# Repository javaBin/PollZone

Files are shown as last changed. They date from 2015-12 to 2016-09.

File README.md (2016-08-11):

# Arduino

Configure your Arduino IDE with ESP8266 support: File -> Preferences, add `http://arduino.esp8266.com/stable/package_esp8266com_index.json` under *Additional Board Manager URLs*.

Open the Board Manager: Tools -> Board -> Board Manager and add the `esp8266` board. Current version: `2.2.0`

# BOM - Bill of materials

For 20 bokser:

* 20 x grønn knapper
* 20 x gule knapper
* 20 x røde knapper
* 6 blanke PCBer
* loddetinn
* 20 NodeMCU 
* 20 usb-kabler (kanskje lange, spør hilde)
* 20 ladere
* 80 x distanseskruer 2-3mm
* 80 x maskinskruer til distanseskruer
* 20 x micro-usb-kontakter
* 60 x 1k ohm motstander
* 60 x 120 ohm til blå led
* 60 x 150 ohm til gul led
* 60 x 150 ohm til rød led
* 60 x kondensator
* 240 sko "ca størrelse 15"
* ledninger 

# TODOs

## Box

Modifiser trekasse.
- Litt lavere
- Skjære ut små hull for "feste-tapper" i led-lysene
- USB-utgang på sidevegg
- Gravere inn logo
- plexiglass/akryl
- 3d-printe mounting-brackets for usb.
- Huske å legg panelet riktig vei slik at "svidde kanter" hanver på innsiden.

Avklaringer:
- 2.4GHz nett i spektrum
- Spør om det er strøm ved bordene

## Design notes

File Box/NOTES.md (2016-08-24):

# 2016-08-23

* første runde: 300mm/s 7%/10% (kjører to ganger pga svg-filen)
* andre runde: 300mm/s 7%/15% (kjører to ganger pga svg-filen)

## Gravering

Test 1: 14mm/s 95% corner, 100% work

Test 2: 9mm/s 75% corner, 100% work. Forsatt noen områder som ikke kuttes. Hjørnene ble mye bedre med en god del mindre effekt.

## Eksperimentering med laserkutter:

1. 150mm/s, 7%/30%
1. 100mm/s, 7%/20%
1. Best: samme som II, 12,5mm ute av fokus

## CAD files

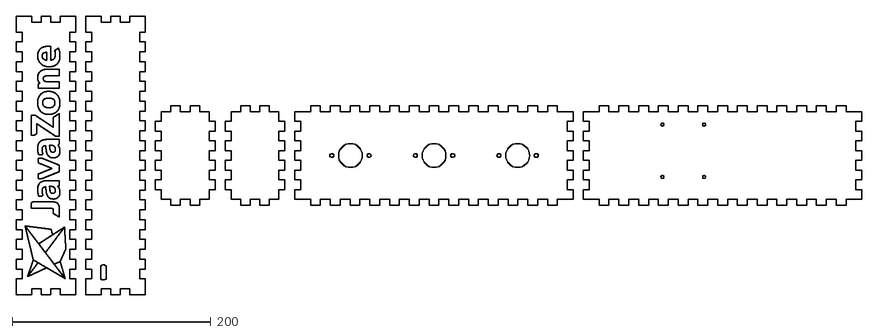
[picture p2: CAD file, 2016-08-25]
Box/box-2016-08-25.dxf
850.0 x 280.0

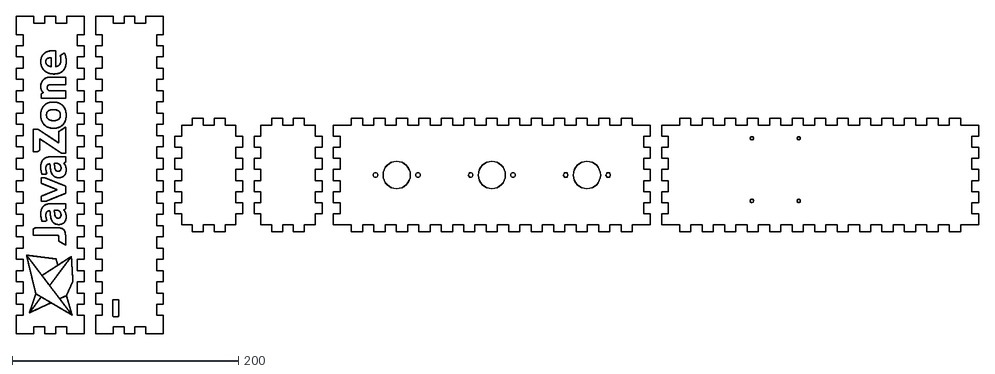
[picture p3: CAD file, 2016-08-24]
Box/box-2016-08-23.dxf
850.0 x 280.0

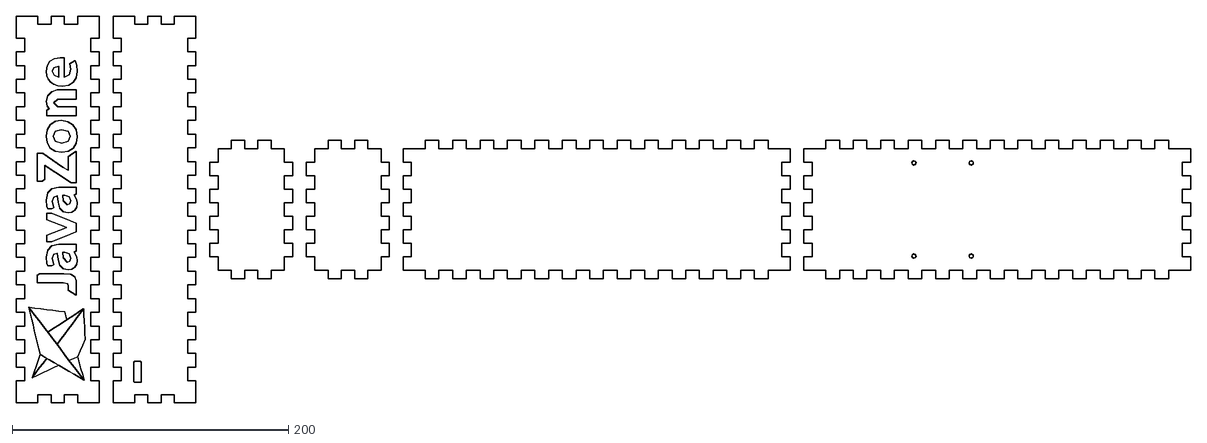
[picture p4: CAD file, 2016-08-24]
Box/box-2016-08-22.dxf
850.0 x 280.0

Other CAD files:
Box/PollZone.fcstd

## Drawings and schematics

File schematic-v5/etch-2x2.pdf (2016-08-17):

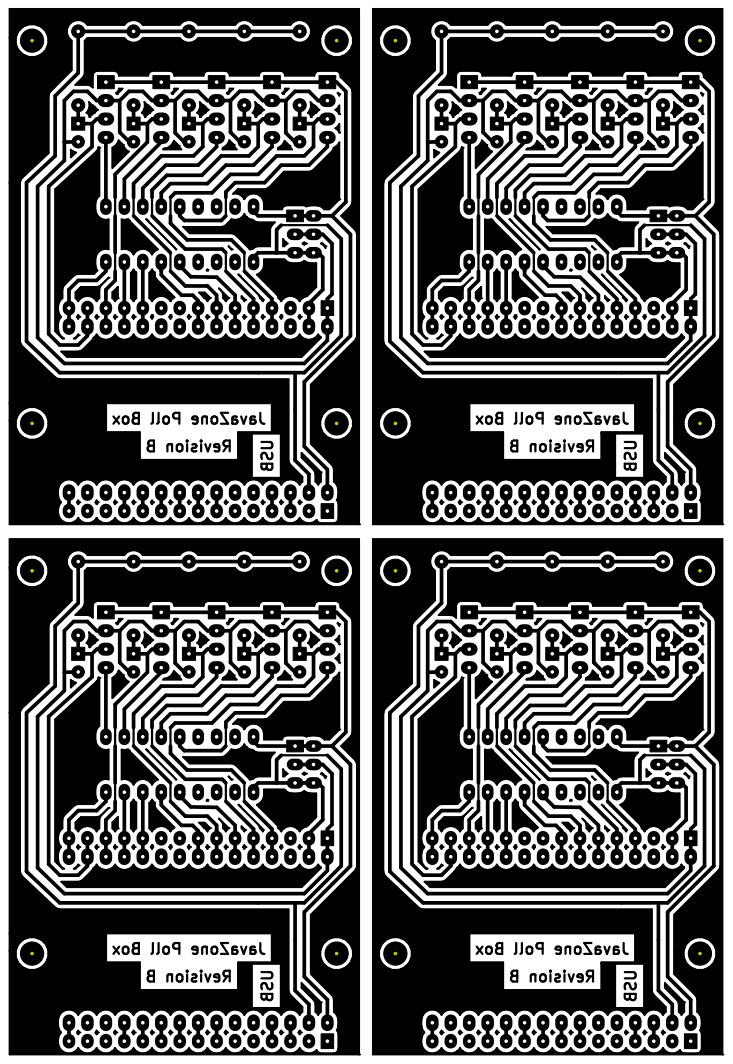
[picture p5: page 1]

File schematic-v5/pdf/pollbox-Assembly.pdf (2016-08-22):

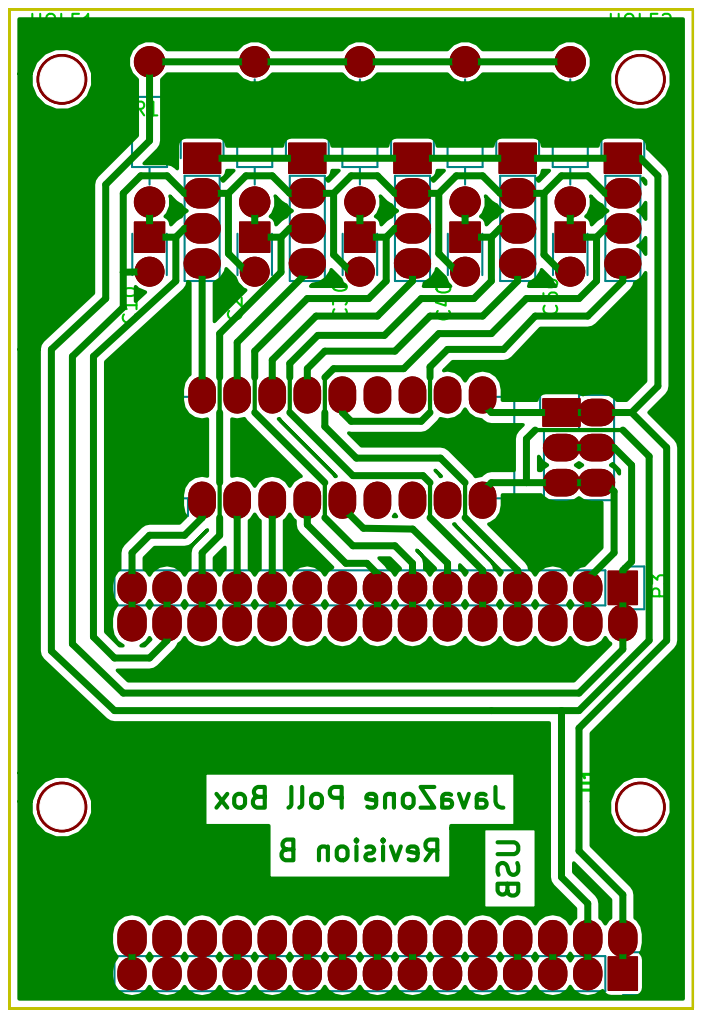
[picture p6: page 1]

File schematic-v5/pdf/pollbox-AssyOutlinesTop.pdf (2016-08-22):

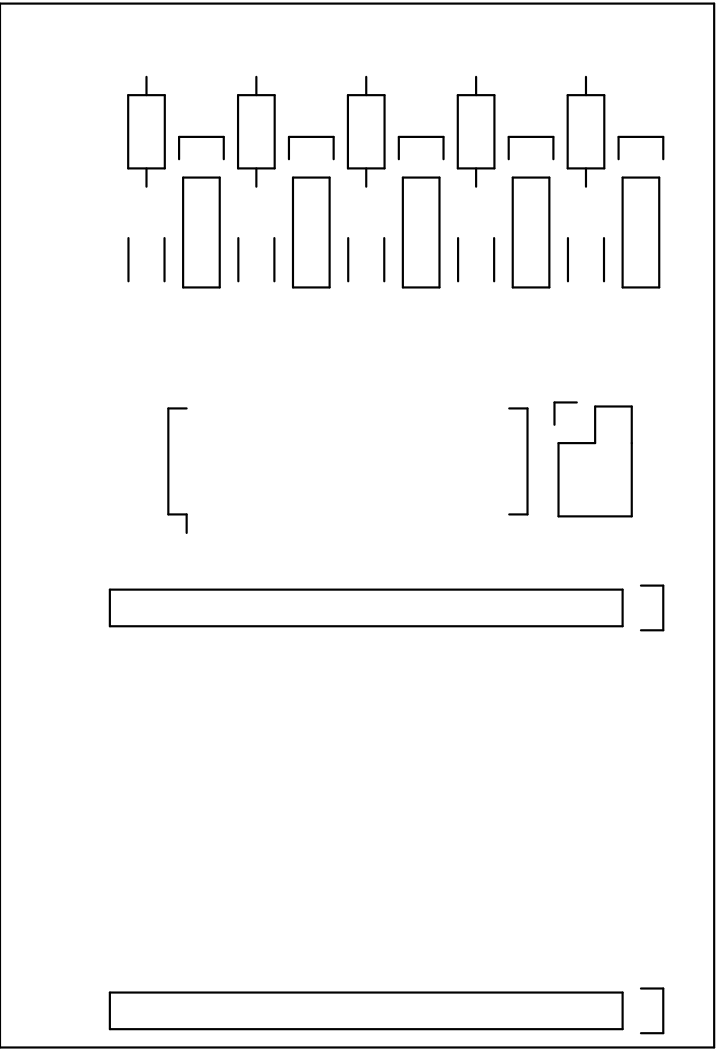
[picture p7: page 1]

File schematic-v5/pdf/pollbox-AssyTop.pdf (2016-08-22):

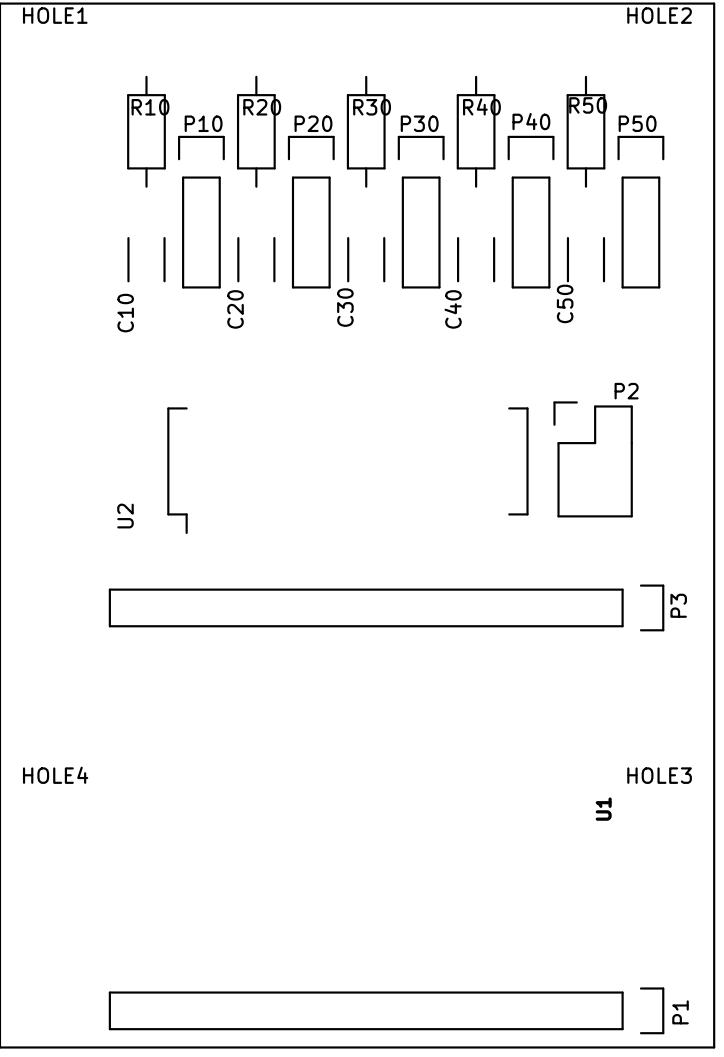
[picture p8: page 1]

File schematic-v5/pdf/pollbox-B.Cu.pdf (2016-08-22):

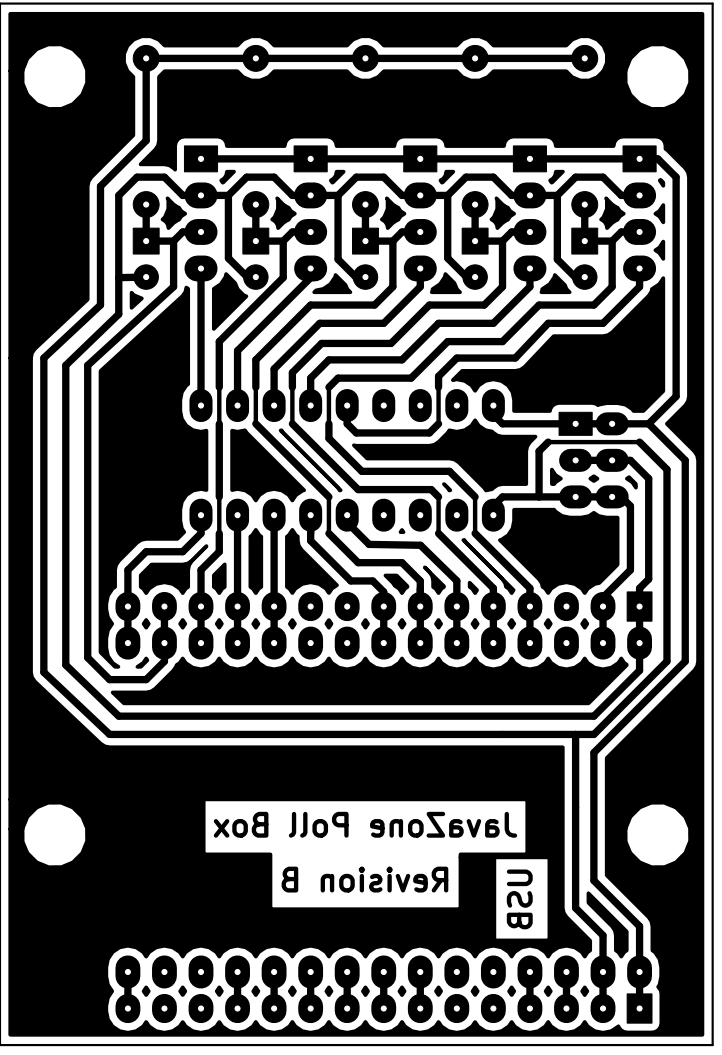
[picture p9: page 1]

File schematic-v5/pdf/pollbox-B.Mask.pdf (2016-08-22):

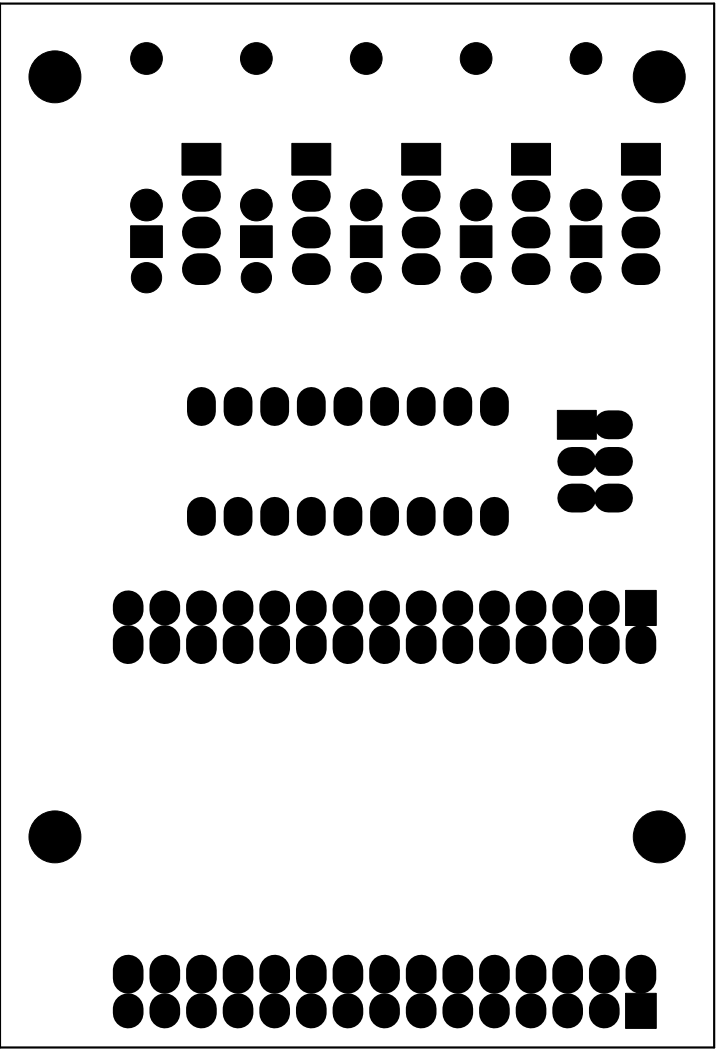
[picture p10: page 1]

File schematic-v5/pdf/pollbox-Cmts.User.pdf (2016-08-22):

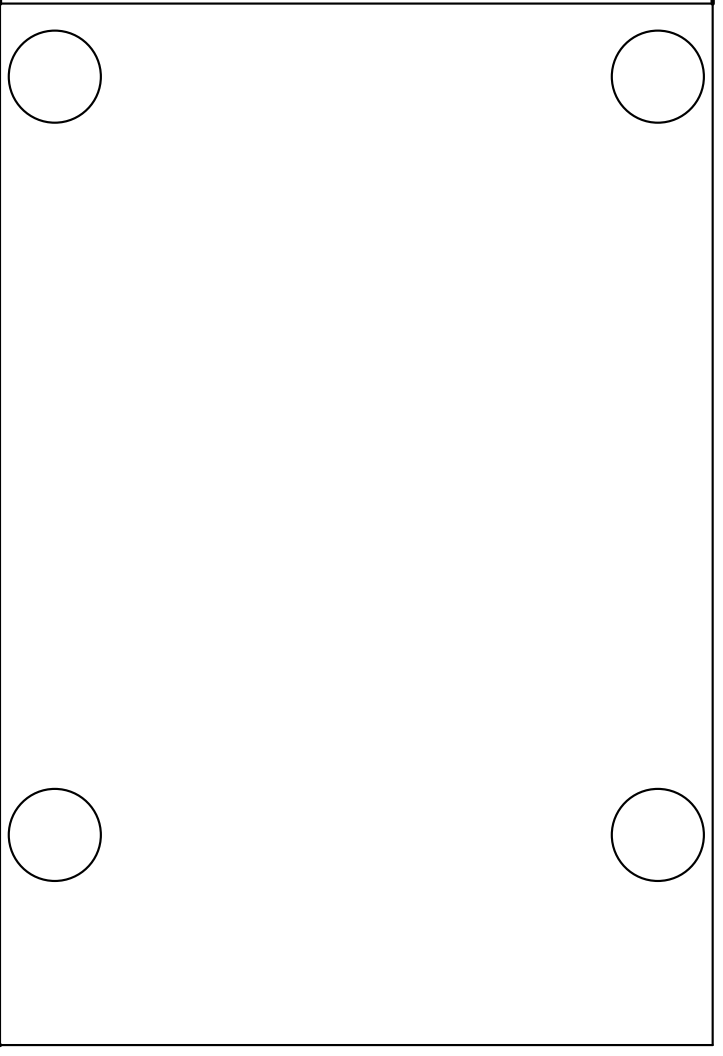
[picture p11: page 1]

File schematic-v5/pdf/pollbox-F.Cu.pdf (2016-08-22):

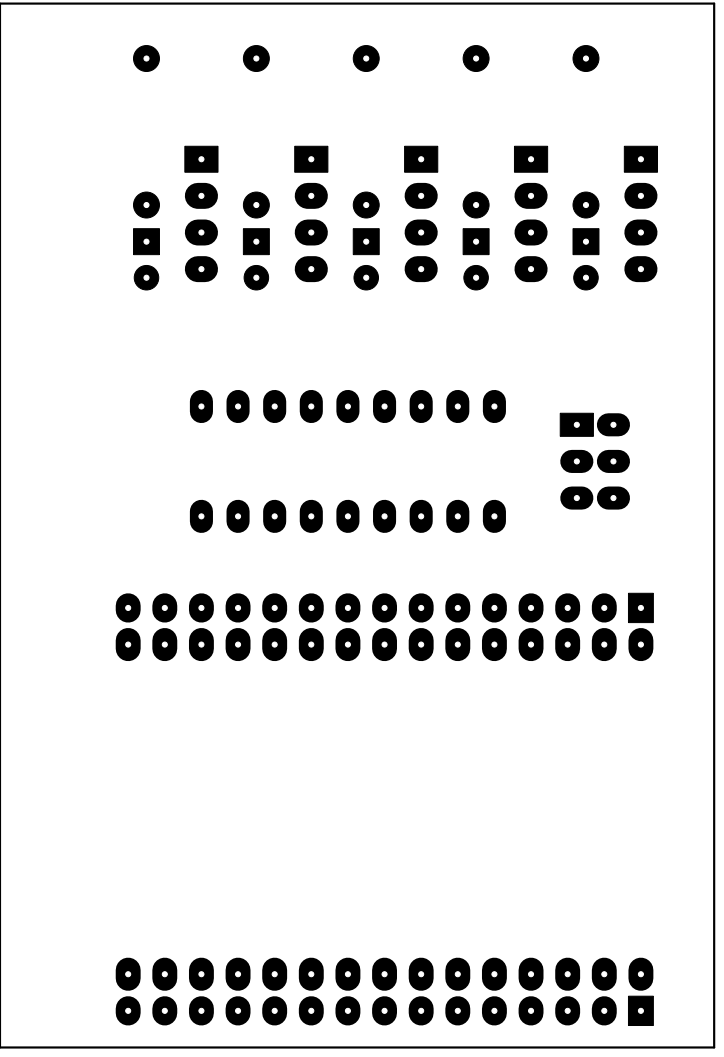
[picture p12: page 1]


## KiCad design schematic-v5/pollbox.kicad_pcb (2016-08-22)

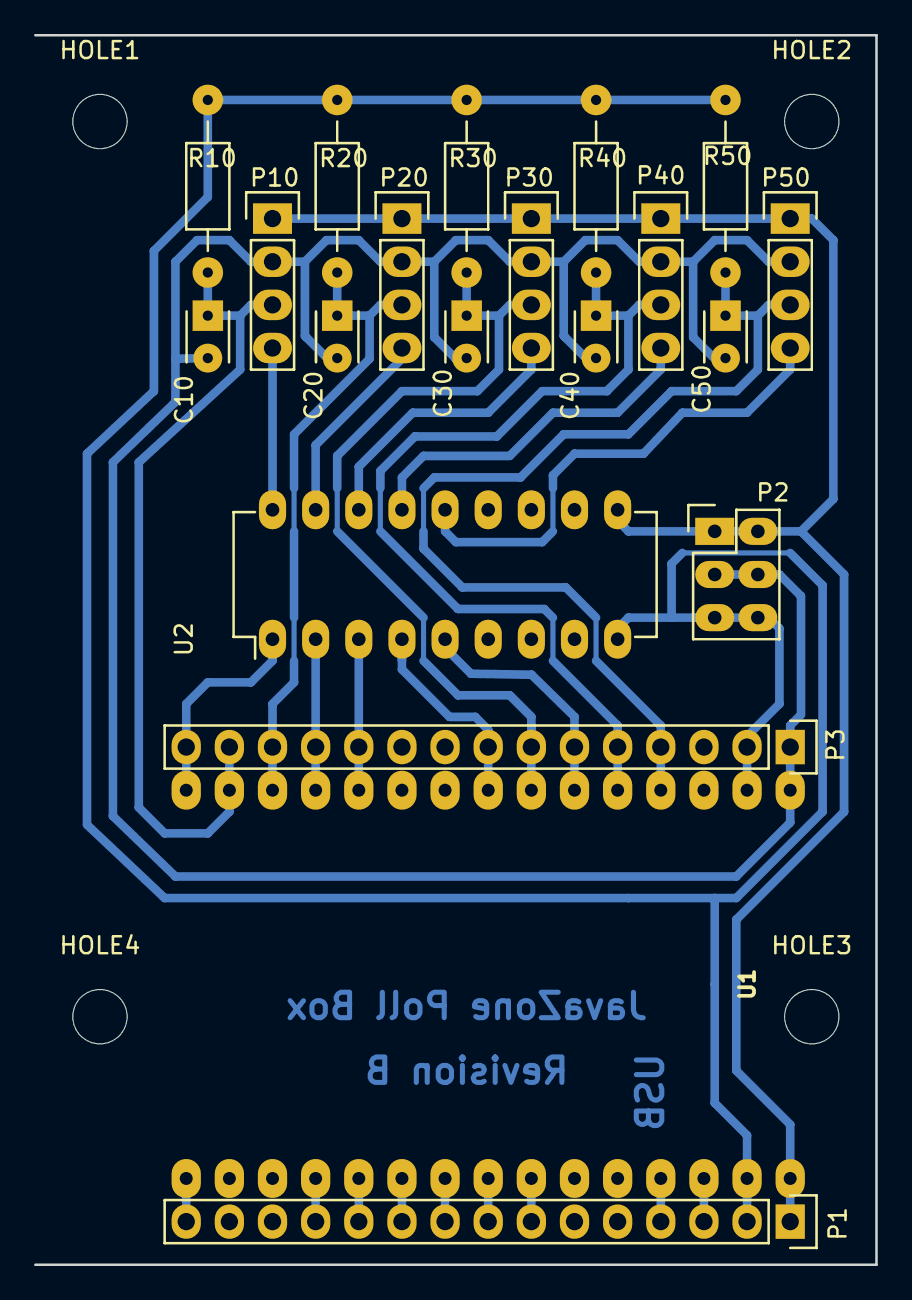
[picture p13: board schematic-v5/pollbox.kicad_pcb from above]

Board: 2 copper layers, 49.5 x 72.4 mm, 24 parts (0 on the bottom side), 27 nets.

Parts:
C10, C20, C30, C40, C50: 100n; C_Disc_D3_P2.5
HOLE1: M1; MountingHole_3.2mm_M3
HOLE2: M2; MountingHole_3.2mm_M3
HOLE3: M4; MountingHole_3.2mm_M3
HOLE4: M3; MountingHole_3.2mm_M3
P1, P3: Pin_Header_Straight_1x15
P2: Power; Pin_Header_Straight_2x03
P10: SW_1; Pin_Header_Straight_1x04
P20: SW_2; Pin_Header_Straight_1x04
P30: SW_3; Pin_Header_Straight_1x04
P40: SW_4; Pin_Header_Straight_1x04
P50: SW_5; Pin_Header_Straight_1x04
R10, R20, R30, R40, R50: 10k; Resistor_Horizontal_RM10mm
U1: NodeMCU_1.0; NodeMCU
U2: ULN2803; DIP-18_W7.62mm_LongPads

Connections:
+3V3: C10.2, C20.2, C30.2, C40.2, C50.2, P2.3, P2.4, P3.1, P10.2, P20.2, P30.2, P40.2, P50.2, U1.30
+5V: P1.1, P2.1, P2.2, P10.1, P20.1, P30.1, P40.1, P50.1, U1.1, U2.10
/AD0: P1.15, U1.15
/CLK: P1.7, U1.7
/CMD: P1.9, U1.9
/EN: P1.4, U1.4
/LED_1: P3.15, U1.16, U2.1
/LED_1_OUT: P10.4, U2.18
/LED_2: P3.12, U1.19, U2.2
/LED_2_OUT: P20.4, U2.17
/LED_3: P3.11, U1.20, U2.3
/LED_3_OUT: P30.4, U2.16
/LED_4: P3.8, U1.23, U2.4
/LED_4_OUT: P40.4, U2.15
/LED_5: P3.6, U1.25, U2.5
/LED_5_OUT: P50.4, U2.14
/SD0: P1.8, U1.8
/SD1: P1.10, U1.10
/SD2: P1.11, U1.11
/SD3: P1.12, U1.12
/SWITCH_1: C10.1, P3.14, P10.3, R10.1, U1.17
/SWITCH_2: C20.1, P3.13, P20.3, R20.1, U1.18
/SWITCH_3: C30.1, P3.7, P30.3, R30.1, U1.24
/SWITCH_4: C40.1, P3.5, P40.3, R40.1, U1.26
/SWITCH_5: C50.1, P3.4, P50.3, R50.1, U1.27
/~RST: P1.3, U1.3
GND: P1.2, P2.5, P2.6, P3.2, R10.2, R20.2, R30.2, R40.2, R50.2, U1.2, U1.29, U2.9

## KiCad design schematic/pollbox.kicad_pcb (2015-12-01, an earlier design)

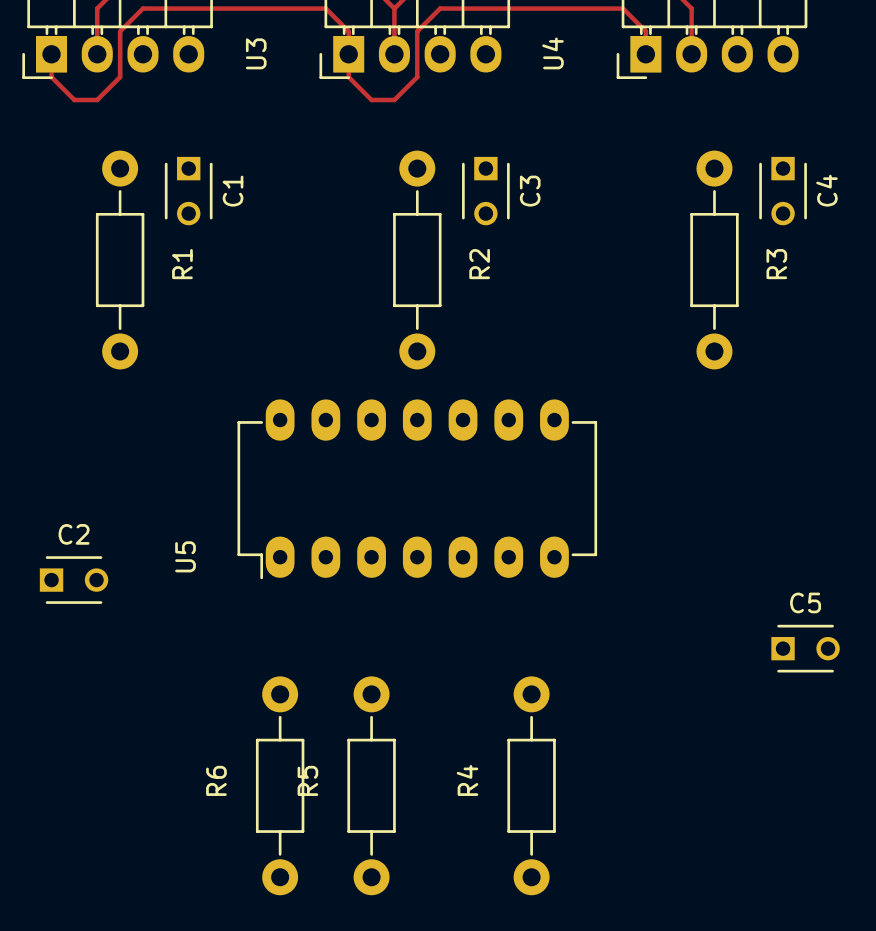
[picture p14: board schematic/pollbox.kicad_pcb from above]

Board: 2 copper layers, 15 parts (0 on the bottom side), 12 nets.

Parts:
C1, C2, C3, C4, C5: 100n; C_Disc_D3_P2.5
R1, R2, R3: 10k; Resistor_Horizontal_RM10mm
R4, R5, R6: 1k; Resistor_Horizontal_RM10mm
U2, U3, U4: BIG_BUTTON; Pin_Header_Angled_1x04
U5: LM3046; DIP-14_W7.62mm_LongPads

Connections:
+3V3: C1.2, C3.2, C4.2, C5.2, U2.1, U3.1, U4.1
+5V: C2.1, U2.2, U3.2, U4.2
GND: C2.2, C5.1, R1.2, R2.2, R3.2, U5.7, U5.10, U5.13
unnamed: C1.1, R1.1, U2.4
unnamed: C3.1, R2.1, U3.4
unnamed: C4.1, R3.1, U4.4
unnamed: R4.2, U5.6
unnamed: R5.2, U5.9
unnamed: R6.2, U5.12
unnamed: U2.3, U5.14
unnamed: U3.3, U5.11
unnamed: U4.3, U5.8

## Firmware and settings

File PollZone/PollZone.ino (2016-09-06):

#include "PollClient.h"
#include "PollState.h"
#include "Buttons.h"
#include "Cfg.h"
#include "utils.h"
#include <Arduino.h>
#include <ArduinoOTA.h>

Cfg cfg(__DATE__ " " __TIME__);
PollClient* pollClient;
PollState* pollState;
Buttons buttons;

int rotateSequence = 0;

void setupOta() {
  static fixed_interval_timer<1000> ota_blink;

  ArduinoOTA.onStart([]() {
    Serial.println("Starting OTA upgrade");
    ota_blink.reset();
    buttons.set_ota_mode(true);
  });
  ArduinoOTA.onEnd([]() {
    buttons.set_ota_mode(false);
    Serial.println("\nOTA upgrade complete");
  });
  ArduinoOTA.onProgress([](unsigned int progress, unsigned int total) {
    Serial.printf("Progress: %u%%\r", (progress / (total / 100)));
    buttons.loop();
  });
  ArduinoOTA.onError([](ota_error_t error) {
    Serial.printf("Error[%u]: ", error);
    if (error == OTA_AUTH_ERROR) Serial.println("Auth Failed");
    else if (error == OTA_BEGIN_ERROR) Serial.println("Begin Failed");
    else if (error == OTA_CONNECT_ERROR) Serial.println("Connect Failed");
    else if (error == OTA_RECEIVE_ERROR) Serial.println("Receive Failed");
    else if (error == OTA_END_ERROR) Serial.println("End Failed");
  });

  Serial.print("OTA Password: ");
  if (cfg.otaPassword.length()) {
    Serial.println(cfg.otaPassword);
    ArduinoOTA.setPassword(cfg.otaPassword.c_str());
  } else {
    Serial.println("Not set");
  }

  ArduinoOTA.begin();
}

// the setup function runs once when you press reset or power the board
void setup() {
  Serial.begin(115200);
  delay(100);

  Serial.print("Build timestamp: ");
  Serial.println(cfg.buildTimestamp);

  cfg.loadConfig();
  Serial.println("Configuration:");
  Serial.print("Wlan SSID:     ");
  Serial.println(cfg.wifiSsid);
  Serial.print("Wlan Password: ");
  Serial.println(cfg.wifiPassword);
  Serial.print("MQTT Broker:   ");
  Serial.println(cfg.mqttBroker);
  Serial.print("Serial:        ");
  if (cfg.serial.length()) {
    Serial.println(cfg.serial);
  } else {
    Serial.println("Not set");
  }
  Serial.print("Name:          ");
  if (cfg.name.length()) {
    Serial.println(cfg.name);
  } else {
    Serial.println("Not set");
  }

  pollClient = new PollClient(cfg);
  buttons.setup();
  pollState = new PollState(pollClient, buttons);
  pollState->setup();

  setupOta();
}

// the loop function runs over and over again until power down or reset
void loop() {
  ArduinoOTA.handle();

  buttons.loop();
  pollClient->loop();
  pollState->loop();
}

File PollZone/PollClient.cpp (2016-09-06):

#include "PollClient.h"
#include "Cfg.h"
#include <PubSubClient.h>
#include <WiFiUdp.h>
#include <WiFiServer.h>
#include <WiFiClient.h>
#include <ESP8266WiFiMulti.h>
#include <ESP8266WiFi.h>

PollClient* PollClient::instance;

PollClient::PollClient(
  Cfg &cfg) :
  cfg(cfg),
  wifiClient(),
  client(wifiClient),
  mac(WiFi.macAddress()),
  clientId("pollbox-" + mac),
  voteTopic("pollerbox/" + mac + "/vote"),
  onlineTopic("pollerbox/" + mac + "/online"),
  serialTopic("pollerbox/" + mac + "/serial"),
  nameTopic("pollerbox/" + mac + "/name"),
  wifiTopic("pollerbox/" + mac + "/wifi"),
  brokerTopic("pollerbox/" + mac + "/mqtt-broker"),
  ipTopic("pollerbox/" + mac + "/ip"),
  otaPasswordTopic("pollerbox/" + mac + "/ota-password"),
  buildTimestampTopic("pollerbox/" + mac + "/build-timestamp") {
};

// This is called both by the main setup(), but also when reconfigured.
void PollClient::setup() {
  if (client.connected()) {
    Serial.print("Disconnecting from MQTT broker.");
    client.disconnect();
  }

  Serial.print("Connecting to AP ");
  Serial.println(cfg.wifiSsid);

  WiFi.begin(cfg.wifiSsid.c_str(), cfg.wifiPassword.c_str());

  const int default_reset_countdown = 25;
  int reset_countdown = default_reset_countdown;

  const int default_status_countdown = 10;
  int status_countdown = default_status_countdown;
  while (WiFi.status() != WL_CONNECTED) {
    delay(500);
    if (--reset_countdown == 0) {
      reset_countdown = default_reset_countdown;
      status_countdown = default_status_countdown;
      Serial.println();
      Serial.println("Reconnecting WiFi");
      WiFi.reconnect();
    } else if (--status_countdown == 0) {
      status_countdown = default_status_countdown;

      Serial.print(" Status: ");
      Serial.println(WiFi.status());
    } else {
      Serial.print(".");
    }
  }
  Serial.println();
  Serial.println("WiFi connected");
  Serial.printf("IP address: ");
  Serial.println(WiFi.localIP());
  Serial.print("MAC address: ");
  Serial.println(mac);

  client.setServer(cfg.mqttBroker.c_str(), 1883);
  instance = this;
  client.setCallback(onMqttMsg);
  ensureConnected();
}

void PollClient::onMqttMsg(char* _topic, byte* payload, unsigned int length) {
  String topic(_topic);
  String value;

  value.reserve(length + 1);
  for (unsigned int i = 0; i < length; i++) {
    value += static_cast<char>(payload[i]);
  }

  instance->onMsg(topic, value);
}

void PollClient::onMsg(const String& topic, const String& payload) {
  if (topic.endsWith("/serial")) {
    if (payload.length()) {
      Serial.print("Setting serial: ");
      Serial.println(payload);
      cfg.setSerial(payload);
    }
  } else if (topic.endsWith("/name")) {
    if (payload.length()) {
      Serial.print("Setting name: ");
      Serial.println(payload);
      cfg.setName(payload);
    }
  } else if (topic.endsWith("/wifi")) {
    auto separator = payload.indexOf(':');
    if (separator == -1) {
      return;
    }

    String ssid = payload.substring(0, separator);
    String password = payload.substring(separator + 1);

    cfg.setWifi(ssid, password);
    setup();
  } else if (topic.endsWith("/mqtt-broker")) {
    cfg.setMqttBroker(payload);
    setup();
  } else if (topic.endsWith("/ota-password")) {
    Serial.print("Setting OTA password: ");
    Serial.println(payload);
    cfg.setOtaPassword(payload);
  }
}

void PollClient::ensureConnected() {
  while (!client.connected()) {
    Serial.print("Connecting to MQTT broker...");
    if (client.connect(clientId.c_str(), onlineTopic.c_str(), 0, true, "false")) {
      Serial.println("connected");

      client.publish(onlineTopic.c_str(), "true", true);
      client.subscribe(wifiTopic.c_str());
      client.subscribe(brokerTopic.c_str());
      client.subscribe(otaPasswordTopic.c_str());

      if (cfg.serial.length()) {
        Serial.println("Publishing serial.");
        client.publish(serialTopic.c_str(), cfg.serial.c_str(), true);
        // If you want to reset the ID, uncomment this line
        // client.subscribe(serialTopic.c_str());
      } else {
        client.subscribe(serialTopic.c_str());
      }

      if (cfg.name.length()) {
        Serial.println("Publishing name.");
        client.publish(nameTopic.c_str(), cfg.name.c_str(), true);
      } else {
        client.subscribe(nameTopic.c_str());
      }

      Serial.println("Publishing IP");
      client.publish(ipTopic.c_str(), WiFi.localIP().toString().c_str(), true);

      client.publish(buildTimestampTopic.c_str(), cfg.buildTimestamp.c_str(), true);
    } else {
      Serial.printf("failed! rc=");
      Serial.println(client.state());
      // Wait 5 seconds before retrying
      delay(5000);
    }
  }
}

bool PollClient::send(int buttonId) {
  ensureConnected();
  if (client.connected()) {
    return client.publish(voteTopic.c_str(), String(buttonId).c_str(), false);
  } else {
    return false;
  }
}

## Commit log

2015-12-01 o Adding schematic.
    [pollbox.kicad_pcb, pollbox.sch]
2015-12-01 added code for three buttons and reset button
2016-01-19 changed red in to D7 due to unstability issues
    [PollZone.ino]
2016-05-24 refactor: Moved source file to sub folder
    Arduino expects the main source file to be the same
    name as the folder. It's also case sensitive. To be
    able to name the git checkout folder to what we like
    we need to have the files in a sub folder in the git
    structure.
2016-05-24 refactor: shrink PollZone file
    Split the PollZone into PollClient and PollButton. Remove the
    reset button and led control since it wasn't working as
    intended.
2016-05-24 fix: connect to mqtt server
    Connection to the mqtt server was lost in the
    refactroing. Adding it back again.
    [PollClient.cpp, PollZone.ino]
2016-05-24 fix: assign right variable in PollButton
    [PollButton.cpp]
2016-05-24 feat: disable led at setup for pollbutton
2016-05-24 fix: send event only on button release
    [PollButton.cpp]
2016-05-24 fix: ensure connection is up when sending data
    We don't need to keep the connection to the
    server up all the time. Only ensure that we
    have a connection when we need to send data.
    [PollClient.cpp, PollZone.ino]
2016-05-25 fix: remove include fron PollZone.ino
    [PollZone.ino]
2016-05-25 feat: process now return if the button is relased
    The goal is to remove the logic and copling to the
    client in the PollButton. This is the first step
    where we expose a flag to indecate if the button
    have registered a button release event.
2016-05-25 refactor: decopled button and client
    Now we're not sedning the push event inside
    the button class anymore. It's now moved to
    the state class.
2016-05-25 fix: reset counter to print status every 5 sec
    The counter wasn't reseted so we only printed the wifi
    status once.
    [PollClient.cpp]
2016-05-28 feat: remove persisting of messages
    We do not need the last message from the device
    to be stored on the mqtt broker.
    [PollClient.cpp]
2016-05-28 o Schematic with ULN2803.
    [pollbox.dsn, pollbox.kicad_pcb, pollbox.sch]
2016-05-29 feat: change track width on pcb
    [pollbox.kicad_pcb]
2016-05-30 fix: retain should be true for online=true message
    [PollClient.cpp]
2016-08-04 o Schematic v4.
    [pollbox.dsn, pollbox.kicad_pcb, pollbox.sch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]
2016-08-04 o Support both widths of nodemcu boards. o Adding USB label for correct placement.
    [pollbox.kicad_pcb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]
2016-08-04 o Filling zones. o Adding drill holes.
    [pollbox.kicad_pcb, pollbox.sch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]
2016-08-04 o Selecting 'Small holes' when plotting.
    [pollbox.kicad_pcb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]
2016-08-07 o Adding build setup to use kicad-utils to generate schematic-v4.h from the KiCAD schematic.
    [pollbox.sch]
2016-08-09 o Adding dimmensions on layout.
    [pollbox.kicad_pcb]
2016-08-10 o Start of revision B board.
    [pollbox.dsn, pollbox.kicad_pcb, pollbox.sch]
2016-08-15 o Completing routing of board v5.
    [pollbox.kicad_pcb, pollbox.sch]
2016-08-15 o Refreshing PDFs from updated CMake tools. o Cleaning up header and PDF generation for v4 and adding for v5 board.
2016-08-17 rewire d0 and d1
    To enable interrupt on button
    [pollbox.kicad_pcb, pollbox.sch]
2016-08-17 cleanup some tracks
    [pollbox.kicad_pcb]
2016-08-17 bigger pads
    [pollbox.kicad_pcb]
2016-08-17 reduce islands
    [pollbox.kicad_pcb]
2016-08-17 fix conflict with mounting holes
    [pollbox.kicad_pcb]
2016-08-17 some more routes cleanup
    [pollbox.kicad_pcb]
2016-08-17 o Shrinking the board size so we can fit 2x2 on a single board when etching. o Fixing too large NodeMCU footprint. Double checking, yay!
    [pollbox.kicad_pcb, pollbox.sch]
2016-08-18 add missing wires
    [pollbox.kicad_pcb]
2016-08-18 fixed slik screen stuff
    [pollbox.kicad_pcb]
2016-08-18 more solder and silk mask stuff
    [pollbox.kicad_pcb]
2016-08-19 add gerber files
    Used for production at PCBWay
    [pollbox-B.CrtYd.gbr, pollbox-B.Cu.gbr, pollbox-B.Mask.gbr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]
2016-08-22 o Adding a Cfg class to contain the current configuration. Supports reading and writing the configuration. o Adding support for OTA (Over-the-air) uploading of firmware. o Adding support for reconfig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
    [Cfg.cpp, PollButton.cpp, PollClient.cpp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]
2016-08-22 o Adjusting grid and aux origin so the print looks better.
    [pollbox.kicad_pcb]
2016-08-22 o FreeCAD model of box, revision 2.
    [PollZone.fcstd, box.dxf]
2016-08-22 o Improved logo where the points actually meet each other.
    [PollZone.fcstd, box-2016-08-22.dxf, box.dxf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]
2016-08-22 Change led and button pins
2016-08-22 Stop subscribing for every button push
2016-08-24 Much improved model: o Fully modelling the buttons. o Adding a bounding box for the PCB to make sure that everything fits. o Adding mount holes for the PCB.
    [PollZone.fcstd, box-2016-08-22.dxf]
2016-08-24 o DXF and Auto Laser project files.
    [box-2016-08-23.dxf]
2016-08-25 o Correcting board placement holes.
    [PollZone.fcstd, box-2016-08-25.dxf]
2016-09-06 o Improved button leds, adding constant blinking
